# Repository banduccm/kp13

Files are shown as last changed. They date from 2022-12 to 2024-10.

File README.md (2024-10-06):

# Keypad #

This is an attempt to design a serviceable replacement the long-discontinued G13 "gameboard".

## PCB ##

The PCB design depends on symbols from a few libraries:

- <https://github.com/stormbard/Keyboard.pretty> for the hotswap switch footprints
- <https://github.com/drewgates/kb2040-kicad> for the Adafruit KB2040 footprint, symbol, and step file
- <https://grabcad.com/library/kailh-hotswap-mx-1> for the hot-swap socket step file (requires registration)

### Board Layout ###

The G13 had 22 "G" keys, 2 thumb keys, and an analog stick with a click (in addition to some other buttons not
important to this effort).

This initial project contains the main board with 22 keys and 2 pushbuttons intended to be used to switch
layers in QMK. It also includes a header with 2 rows and 6 columns for an expansion board (i.e, the thumb
buttons).

The KB2040 was selected due to easy availability, compatibility with the Pro Micro pinout, and a USB-C port.
Other Pro Micro-compatible boards may work, but take care to skip the D+/D- pins from the KB2040.

## Plates ##

The switch mounting plates for this project were initially designed using swillkb's
[Plate & Case Builder](http://builder.swillkb.com/) tool, then imported into qcad for manipulation.

Experimental baseplates for both the keypad and full-size thumb pod are included, as are 3d-printable spacers
to sit between the plates and PCB.

### Keyboard Layout ###

This layout is used by both the plate builder and the
[Keyboard Layout Editor](http://www.keyboard-layout-editor.com) tool:

```text
[{x:3}, "C0", "C1"],
["G1","G2","G3","G4","G5","G6","G7"],
["G8","G9","G10","G11","G12","G13","G14"],
[{x:0.75,w:1.25},"G15","G16","G17","G18",{w:1.25},"G19"],
[{x:1,w:2},"G20","G21",{w:2},"G22"],
[{x:8.75}, "Stick ↑"],
[{x:7.25}, "G23", "Stick ←", "Stick →"],
[{x:7}, "G24", {x:0.75}, "Stick ↓" ],
[{x:8}, "G25", "G26"]
```

For Via (with some extra design flavor), this is:

```text
[{x:3},"3,4","3,5"],
["0,0","0,1","0,2","0,3","0,4","0,5","1,0"],
["1,1","1,2","1,3","1,4","1,5","2,0","2,1"],
[{x:0.75,w:1.25},"2,2","2,3","2,4","2,5",{w:1.25},"3,0"],
[{x:1,w:2},"3,1","3,2",{w:2},"3,3"],
[{y:0.75,x:8.75,h:0.75},"4,0"],
[{y:-0.75,x:7.25},"5,0"],
[{y:-0.5,x:8.25,h:0.75},"4,1",{h:0.75},"4,3"],
[{y:-0.5,x:7},"5,1"],
[{y:-0.75,x:8.75,h:0.75},"4,2"],
[{y:-0.25,x:8},"5,2","5,3"]

```

 ## Parts ##

 For the first build, the following parts were used:

 ### Plate ###

 The place was ordered from [SendCutSend](https://sendcutsend.com/) in 1.6mm thick 5051 Aluminum.

 ### Electronics ###

 Initial parts were ordered from Adafruit:

- 30x [1N4148 diodes](https://www.adafruit.com/product/1641)
- 20x [6mm Tactile Button switch](https://www.adafruit.com/product/367)
- 40x [Kailh Switch Sockets for MX-compatible Mechanical Keys](https://www.adafruit.com/product/4958)
- 30x [Kailh Mechanical Key Switches - Linear Black](https://www.adafruit.com/product/4953)
- 1x [Adafruit KB2040](https://www.adafruit.com/product/5302)
- ~~1x [GMK Screw-in Stabilizers](https://1upkeyboards.com/shop/parts-and-tools/parts/gmk-screw-in-stabilizers/)~~ _Note: These ended up being incompatible with the plate, see v0.1.0 notes_
- 1x [Durock Plate Mount Stabilizers](https://1upkeyboards.com/shop/parts-and-tools/parts/durock-plate-mount-stabilizers-60-tkl-piano/)

### PCB ###

The PCB was ordered from PCBWay using their Kicad plugin.

## Version Notes ##

### v0.1.0 ###

Generally good news! The parts all fit as expected and the circuit works as designed. No reworks required to
have a functioning 22-key setup.

- The plate is not compatible with the PCB-mount stabilizers.
- The angle on the plate and the angle on the PCB are not the same. This is annoying, but not a functional
 problem.
- n-key rollover works (as expected), but note that QMK defaults to 6KRO. The default keymap uses switch C0
 on Layer 0 to toggle it.

### v0.1.1 ###

Instead of relying on trying to rely on external tools, all the mechanical bits were re-drawn in qcad, which
helpfully makes it extremely simple to import an exported .dxf from KiCAD for tracing and fit checking. The
stabilizer compatibility was not addressed (yet), but at least the angle between the PCB and plate(s) now
aligns.

## v0.2.0 Wishlist ##

During the mechanical design phase, some items were added as a wishlist for a potential second spin of the
"big" board:

- Smaller, optimized thumb-pod connector. Considering using a 1.27mm pitch 10-pin cable (Cortex-M SWD
  connector) to reduce mechanical size.
- Figure out how to use the kb2040's castellated pins to reduce z-height

## Thumb Pods ##

The thumb pod(s) incorporate a 4-way (with diagonals!) thumbstick and 0-4 buttons. There are 2 different
versions: regular (4x 1U MX switch, 1x thumbstick) and mini (2x microswitch, 1x thumbstick). The thumbstick
uses the same matrix positions on each version, so it is possible to populate multiple pods and swap between
them as desired.

The pods feature a notched edge for mounting square against the keypad PCB (or a case holding it). This
ensures the A/B/C/D positions of the thumbstick are square with the keypad.

### Thumbstick ###

- [ALPS RKJXM1015004](https://tech.alpsalpine.com/e/products/detail/RKJXM1015004/)

This thumbstick has 4 switches and can handle diagonal movements as well. It has a "stick click", but this
is not broken out as a dedicated pin, so it's unclear if it is compatible with QMK. In v0.1 of the thumb
pods, the "push" pins are not connected to the key matrix. The "push" pins _are_ on their own net, however,
so they could be hand-wired into the matrix if desired. The same thumbstick is used for both thumb pod
designs.

### Thumb Pod (full size) ###

The regular thumb pod uses the same MX hot-swap sockets and 1U keys as the main keypad to provide 4 switches
surrounding the thumbstick.

Experimental top and bottom plates are provided for the full-size thumb pod.

### Thumb Pod Mini ###

The mini thumb pod closely approximates the original G13 thumb section: two mouse-like microswitches and the
thumbstick. This version will require some sort of housing, as it's not really feasible to hit microswitch
actuators.

#### Electronics ####

- [Kailh GM Microswitch](https://www.kailhswitch.com/micro-switches/mouse-micro-switches/high-click-life-gaming-micro-mouse-switch.html)

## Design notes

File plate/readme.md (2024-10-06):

# Plates

This directory contains drawings for the different plates and spacers used to stack up a full keypad.

They were drawn in qcad, but should be compatible with any tool capable of working with `.dxf` files.

## Keypad

### keypad-plate

This is the top plate for the main keypad into which the switches mount.

### keypad-plate-spacer

This spacer is designed to be printed/manufactured at a thickness of ~3mm (when using 1.6mm-thick material for
the plate - different plate thicknesses may have different needs) and stacks between the PCB and the top
plate.

### keypad-base-plate

This is an experimental baseplate onto which the main keypad can mount. It features a few extra holes for
(theoretical) feet and a slot mechanism for affixing the thumb pod plate.

### keypad-base-plate-spacer

This spacer is designed to be printed/manufactured at a thickness of ~4mm (when using 1.6mm-thick material for
the plate - different plate thicknesses may have different needs) and stacks between the PCB and the base
plate.

## Thumb Pod

At present, plates are only available for the larger of the two thumb pods.

### thumb-pod-plate

This is the top place for the thumb pod into which the switches mount.

### thumb-pod-plate-spacer

This is really just a 3.4mm ID / 7mm OD / 3mm thick washer, because there is precious little space on top of
the thumb pod PCB. Use 3, one for each mounting hole.

### thumb-pod-base-plate

This is an experimental baseplate onto which the thumb pod can mount. It features a few extra holes for
(theoretical) feed and a slot mechanism for attaching to the main keypad.

### thumb-pod-base-plate-spacer

This spacer is designed to be printer/manufactured at a thickness of ~4mm (when using 1.6mm-thick material for
the plate - different plate thicknesses may have different needs) and stacks between the PCB and the base
plate.

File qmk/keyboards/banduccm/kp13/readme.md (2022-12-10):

# keypad

This is an attempt to design a serviceable replacement the long-discontinued G13 "gameboard".

* Keyboard Maintainer: [Mike Banducci](https://github.com/banduccm)
* Hardware Supported:
    * [Adafruit KB2040](https://www.adafruit.com/product/5302)
    * [Custom PCB](https://bitbucket.org/banduccm/keypad/src/master/)

Build example for this keyboard (after setting up your build environment):
```
qmk compile -kb keypad -km default
```

Flashing example for this keyboard:
```
qmk flash -kb keypad -km default
```

See the [build environment setup](https://docs.qmk.fm/#/getting_started_build_tools) and the [make instructions](https://docs.qmk.fm/#/getting_started_make_guide) for more information. Brand new to QMK? Start with our [Complete Newbs Guide](https://docs.qmk.fm/#/newbs).

## Bootloader

Enter the bootloader in 3 ways:

* **Bootmagic reset**: Hold down the key at (0,0) in the matrix (usually the top left key or Escape) and plug in the keyboard
* **Physical reset button**: Briefly press the button on the back of the PCB - some may have pads you must short instead
* **Keycode in layout**: Press the key mapped to `QK_BOOT` if it is available

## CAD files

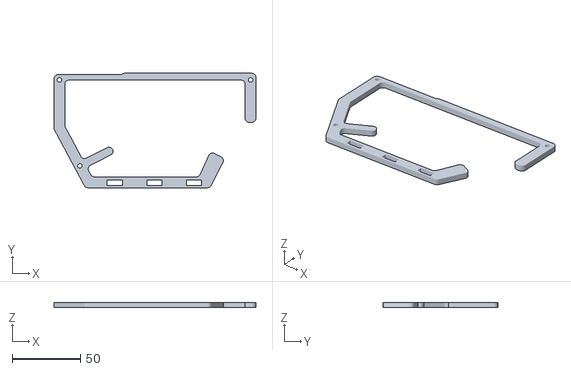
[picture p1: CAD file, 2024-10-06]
plate/keypad-base-plate-spacer-0.1.stl
148.0 x 83.9 x 4.00

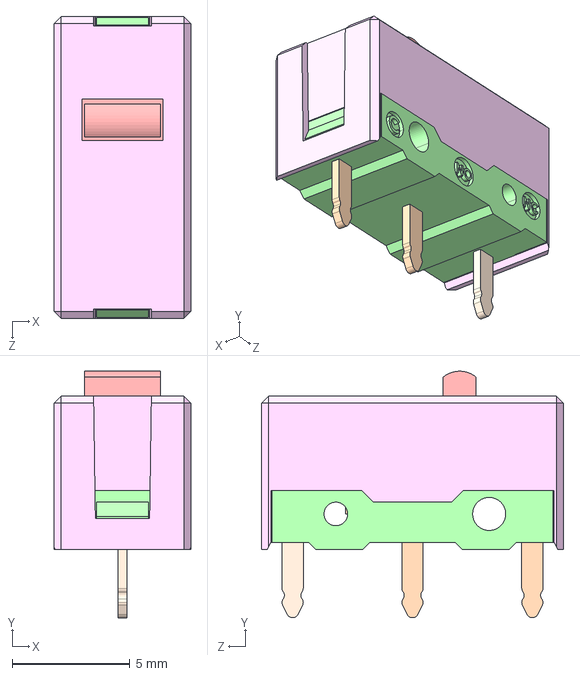
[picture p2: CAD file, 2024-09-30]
thumb_pod/models/SWITCH_MOUSE.STEP
5.80 x 10.4 x 12.8 mm

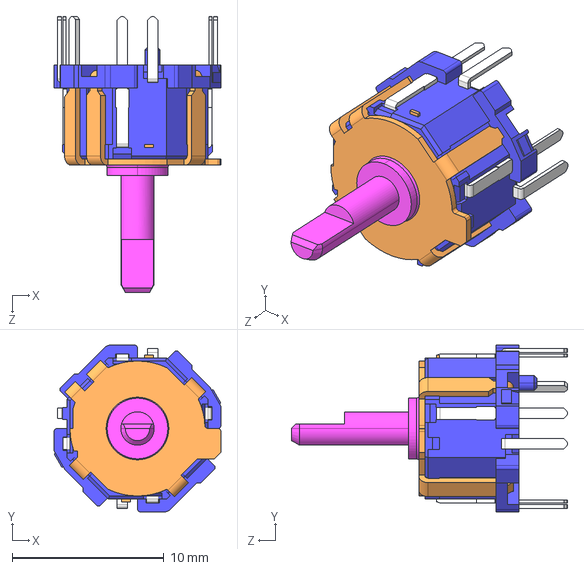
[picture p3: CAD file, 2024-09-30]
thumb_pod/models/RKJXM1015004.STEP
11.0 x 11.0 x 18.2 mm

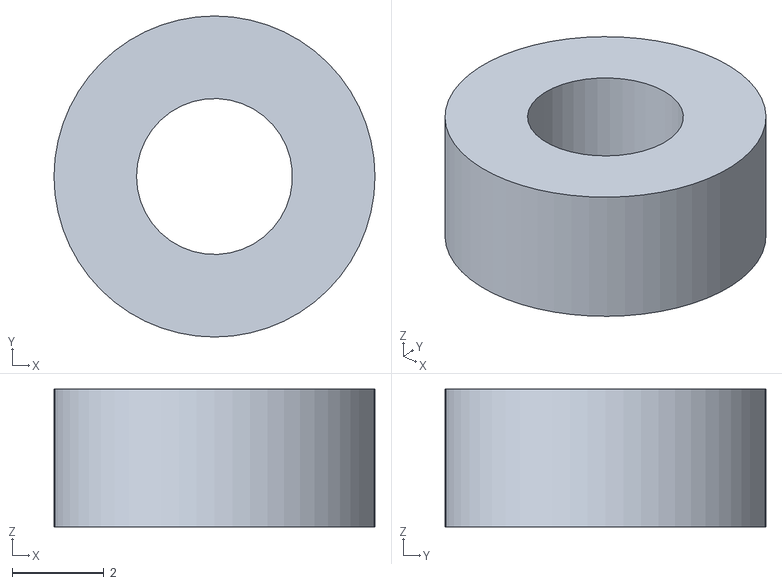
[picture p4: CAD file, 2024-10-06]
plate/thumb-pod-plate-spacer-0.1.stl
7.00 x 7.00 x 3.00

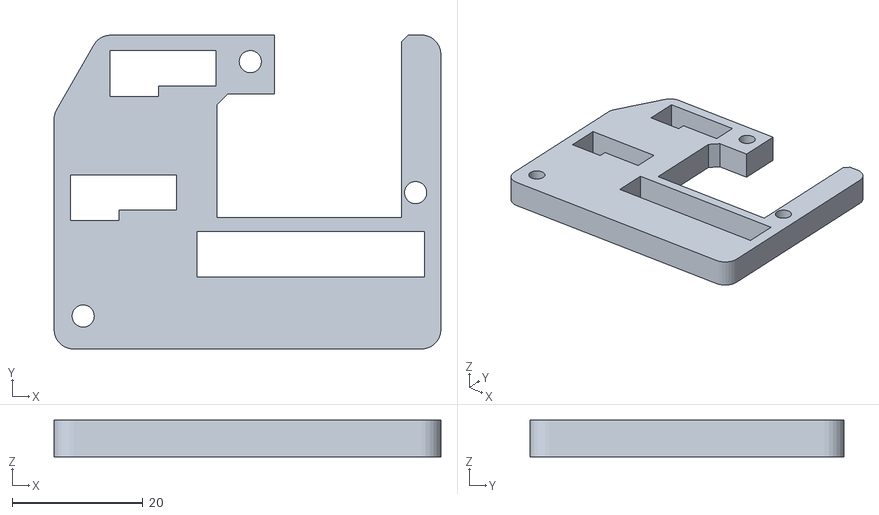
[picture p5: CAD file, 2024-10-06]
plate/thumb-pod-base-plate-spacer-0.1.stl
59.2 x 48.0 x 5.60

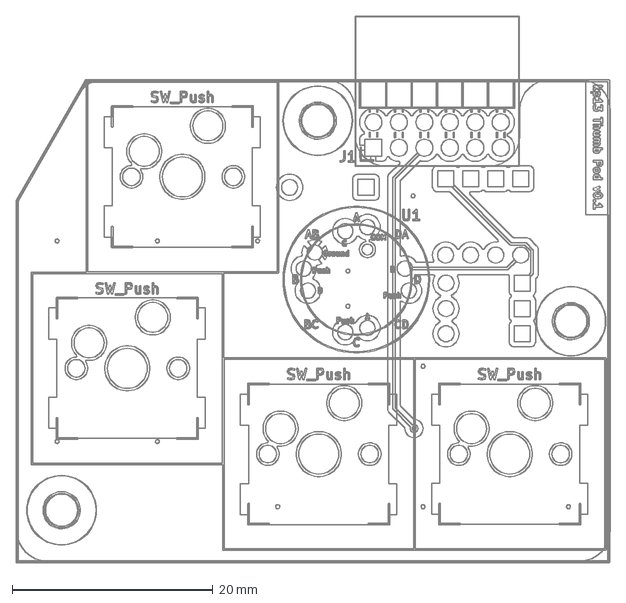
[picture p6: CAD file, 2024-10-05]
plate/thumb-pod-plate-0.1.dxf
59.2 x 54.5 mm

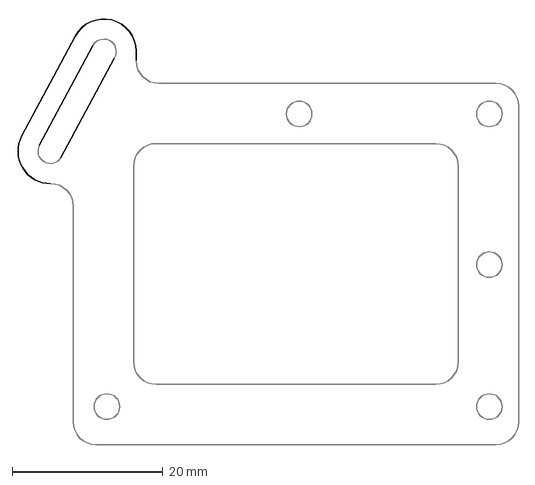
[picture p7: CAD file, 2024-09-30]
plate/thumb-pod-base-plate-0.1.dxf
66.7 x 56.9 mm

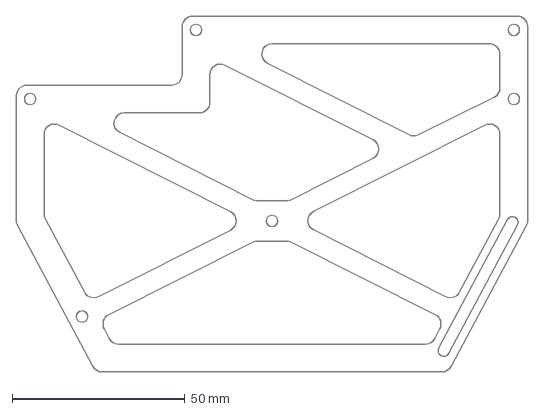
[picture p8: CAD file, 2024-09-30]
plate/keypad-base-plate-0.1.dxf
148.0 x 103.0 mm

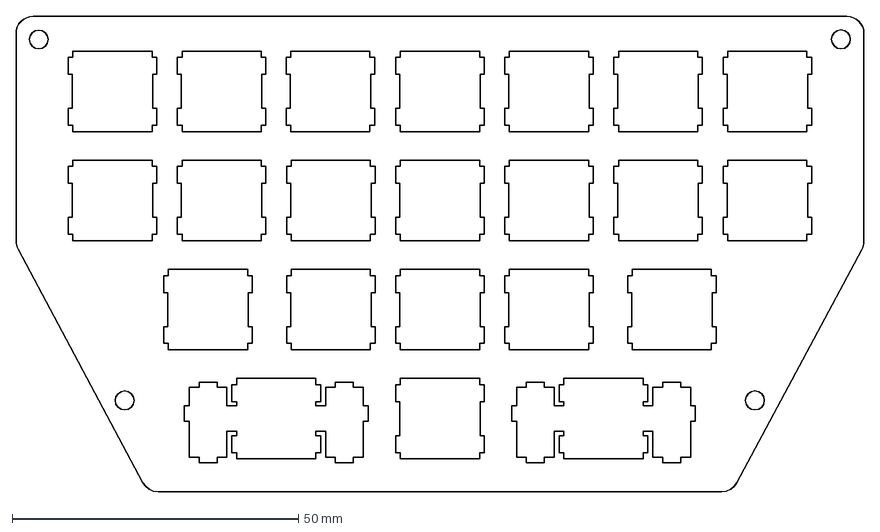
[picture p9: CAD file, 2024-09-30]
plate/keypad-plate-0.1.dxf
148.0 x 83.0 mm

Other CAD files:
plate/keypad-plate-spacer-0.1.stl
plate/keypad-base-plate-spacer-0.1.dxf
plate/keypad-plate-spacer-0.1.dxf
plate/thumb-pod-base-plate-spacer-0.1.dxf
plate/thumb-pod-plate-spacer-0.1.dxf

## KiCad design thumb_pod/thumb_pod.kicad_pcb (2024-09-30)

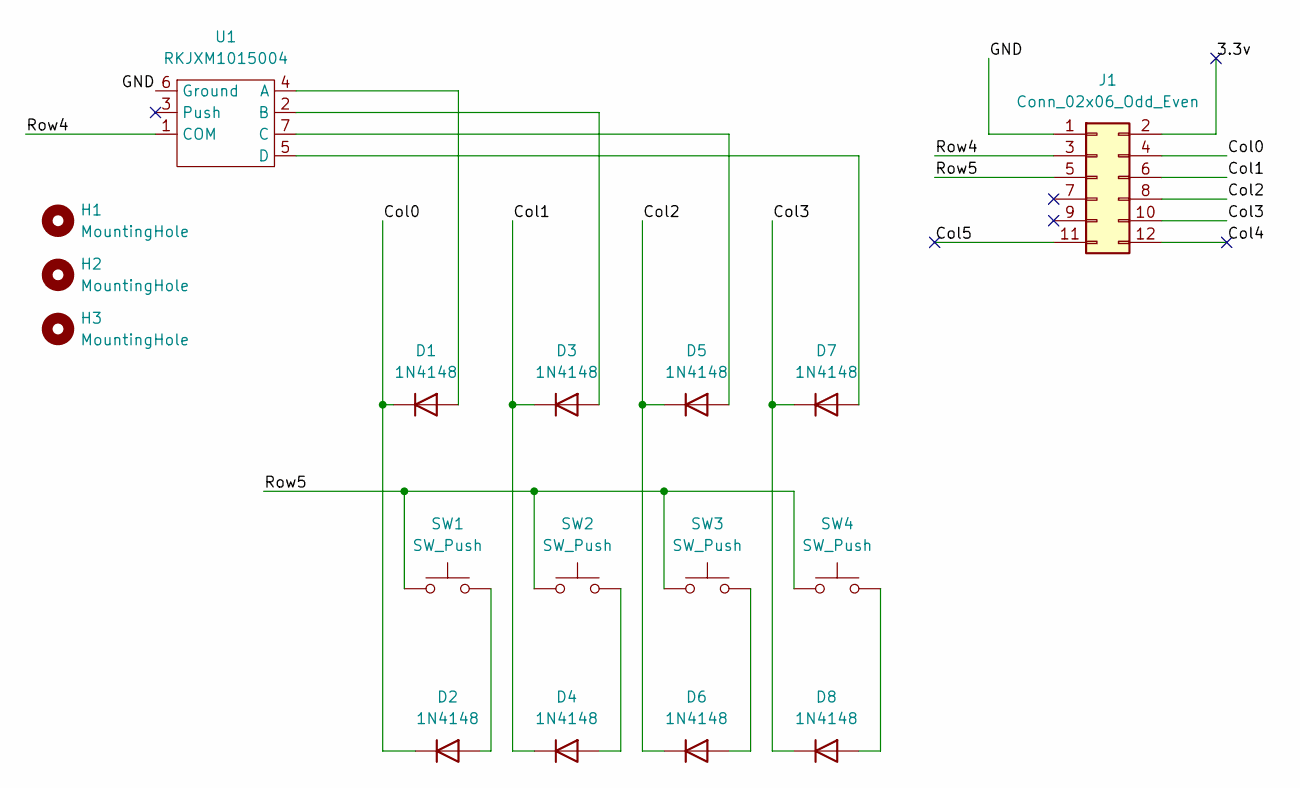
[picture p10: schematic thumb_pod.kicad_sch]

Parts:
D1, D2, D3, D4, D5, D6, D7, D8: 1N4148; D_DO-35_SOD27_P7.62mm_Horizontal
H1, H2, H3: MountingHole; MountingHole_3.2mm_M3
J1: Conn_02x06_Odd_Even; PinHeader_2x06_P2.54mm_Horizontal
SW1, SW2, SW3, SW4: SW_Push; MXOnly-1U-Hotswap
U1: RKJXM1015004

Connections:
/3.3v: J1.2
/Col0: D1.1 (K), D2.1 (K), J1.4
/Col1: D3.1 (K), D4.1 (K), J1.6
/Col2: D5.1 (K), D6.1 (K), J1.8
/Col3: D7.1 (K), D8.1 (K), J1.10
/Col4: J1.12
/Col5: J1.11
/GND: J1.1, U1.6 (Ground)
/Row4: J1.3, U1.1 (COM)
/Row5: J1.5, SW1.1, SW2.1, SW3.1, SW4.1
unnamed: D1.2 (A), U1.4 (A)
unnamed: D2.2 (A), SW1.2
unnamed: D3.2 (A), U1.2 (B)
unnamed: D4.2 (A), SW2.2
unnamed: D5.2 (A), U1.7 (C)
unnamed: D6.2 (A), SW3.2
unnamed: D7.2 (A), U1.5 (D)
unnamed: D8.2 (A), SW4.2

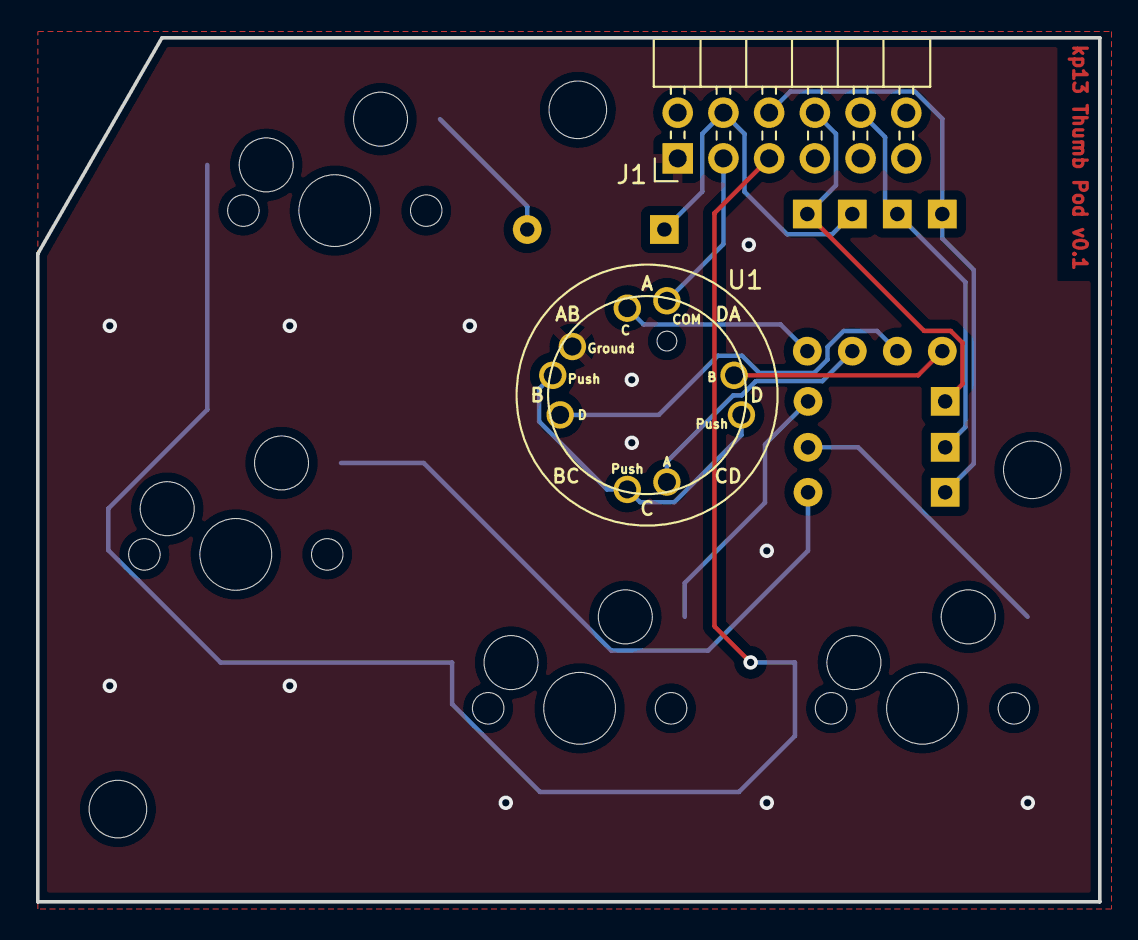
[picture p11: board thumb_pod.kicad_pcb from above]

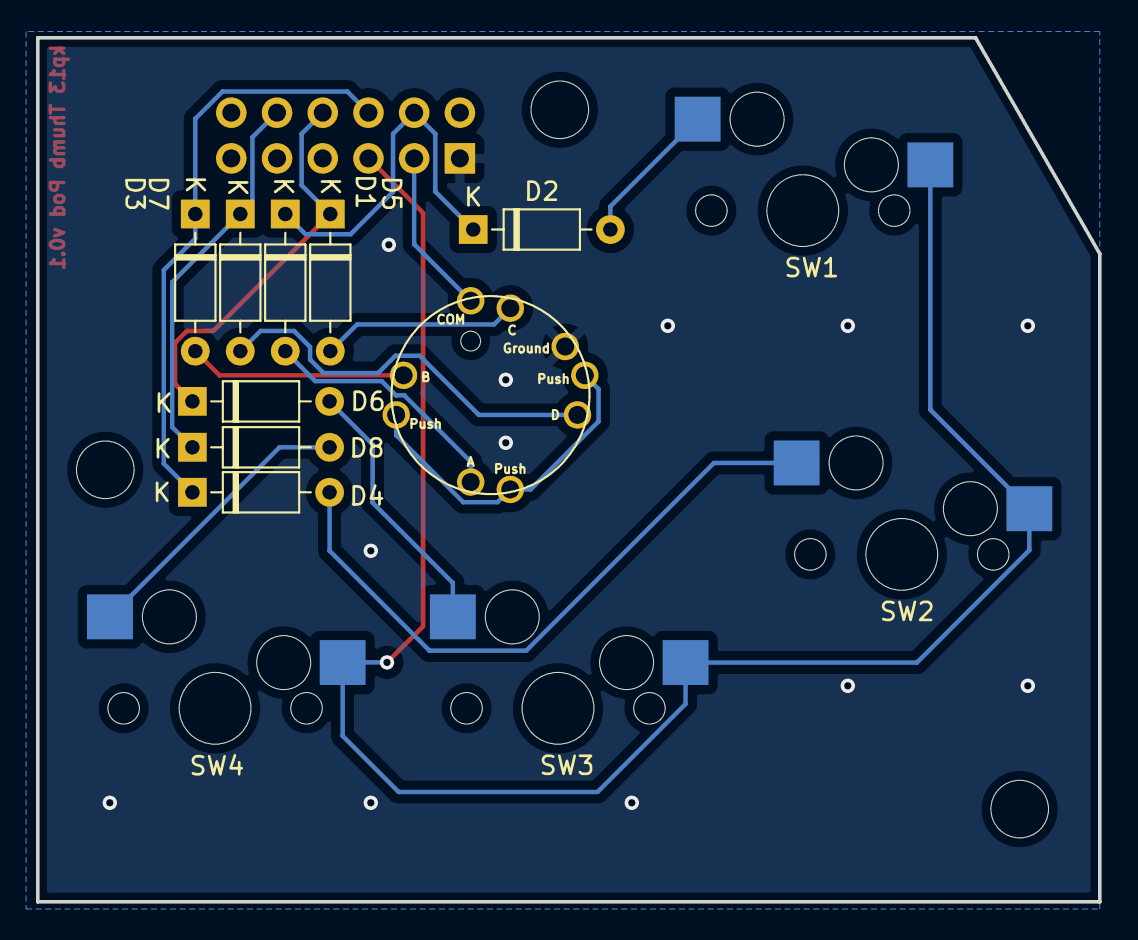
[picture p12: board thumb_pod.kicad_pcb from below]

Board: 2 copper layers, 59.0 x 48.0 mm, 17 parts (8 on the bottom side), 15 nets.

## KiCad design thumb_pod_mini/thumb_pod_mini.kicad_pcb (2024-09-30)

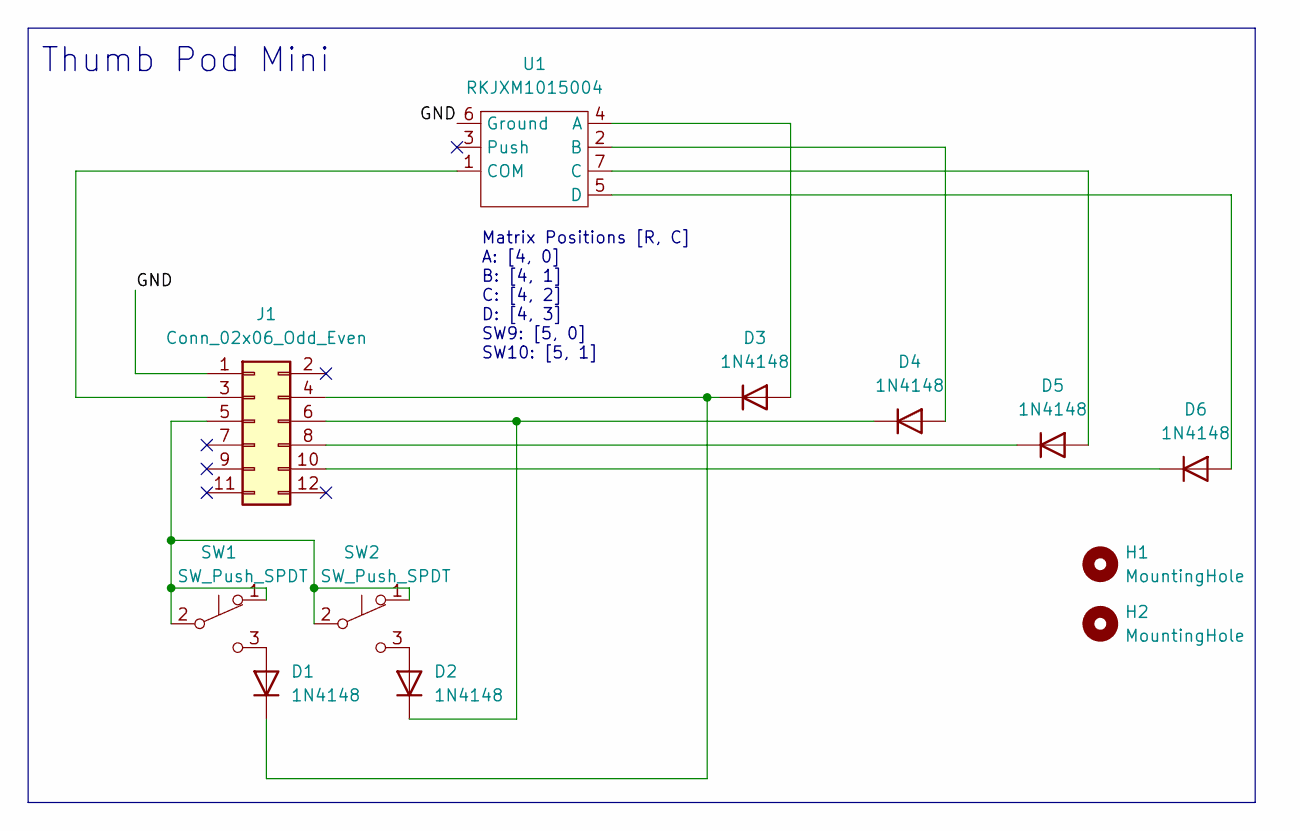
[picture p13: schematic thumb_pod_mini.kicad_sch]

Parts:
D1, D2, D3, D4, D5, D6: 1N4148; D_DO-35_SOD27_P7.62mm_Horizontal
H1, H2: MountingHole; MountingHole_3.2mm_M3
J1: Conn_02x06_Odd_Even; PinHeader_2x06_P2.54mm_Horizontal
SW1, SW2: SW_Push_SPDT; kailh_gm_microswitch
U1: RKJXM1015004

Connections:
/GND: J1.1, U1.6 (Ground)
unnamed: D1.1 (K), D3.1 (K), J1.4
unnamed: D1.2 (A), SW1.3 (C)
unnamed: D2.1 (K), D4.1 (K), J1.6
unnamed: D2.2 (A), SW2.3 (C)
unnamed: D3.2 (A), U1.4 (A)
unnamed: D4.2 (A), U1.2 (B)
unnamed: D5.1 (K), J1.8
unnamed: D5.2 (A), U1.7 (C)
unnamed: D6.1 (K), J1.10
unnamed: D6.2 (A), U1.5 (D)
unnamed: J1.3, U1.1 (COM)
unnamed: J1.5, SW1.1 (A), SW1.2 (B), SW2.1 (A), SW2.2 (B)

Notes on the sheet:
Matrix Positions [R, C] A: [4, 0] B: [4, 1] C: [4, 2] D: [4, 3] SW9: [5, 0] SW10: [5, 1]
Thumb Pod Mini

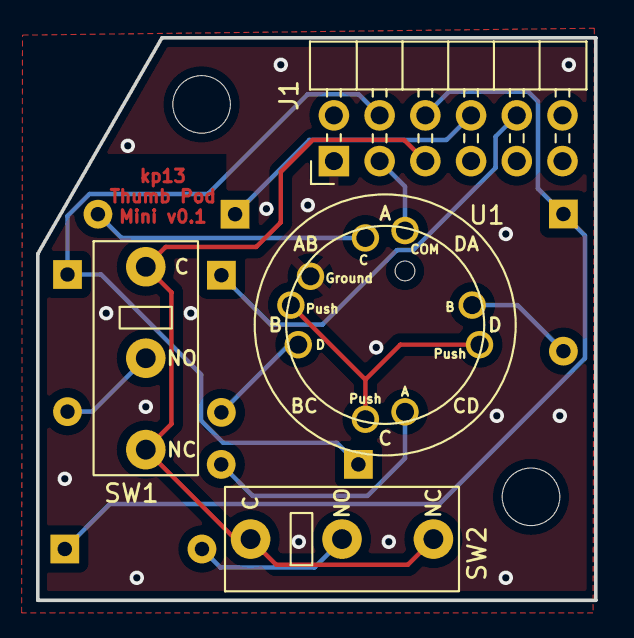
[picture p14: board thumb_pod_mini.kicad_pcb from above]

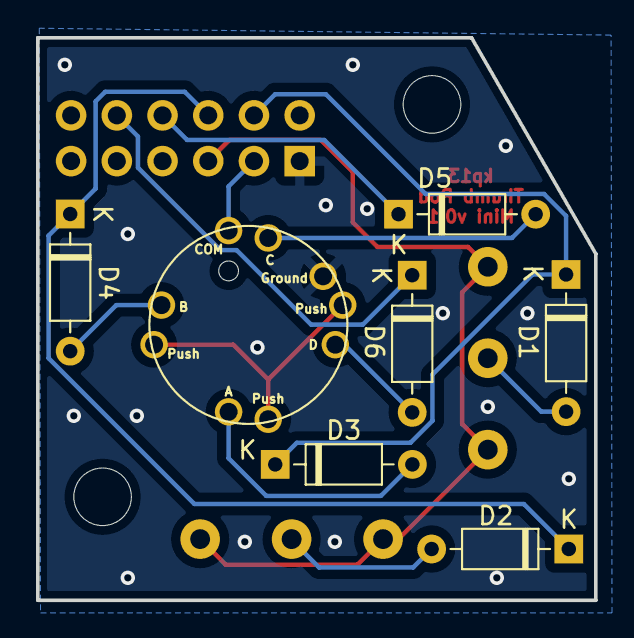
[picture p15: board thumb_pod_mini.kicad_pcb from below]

Board: 2 copper layers, 31.0 x 31.2 mm, 12 parts (6 on the bottom side), 13 nets.

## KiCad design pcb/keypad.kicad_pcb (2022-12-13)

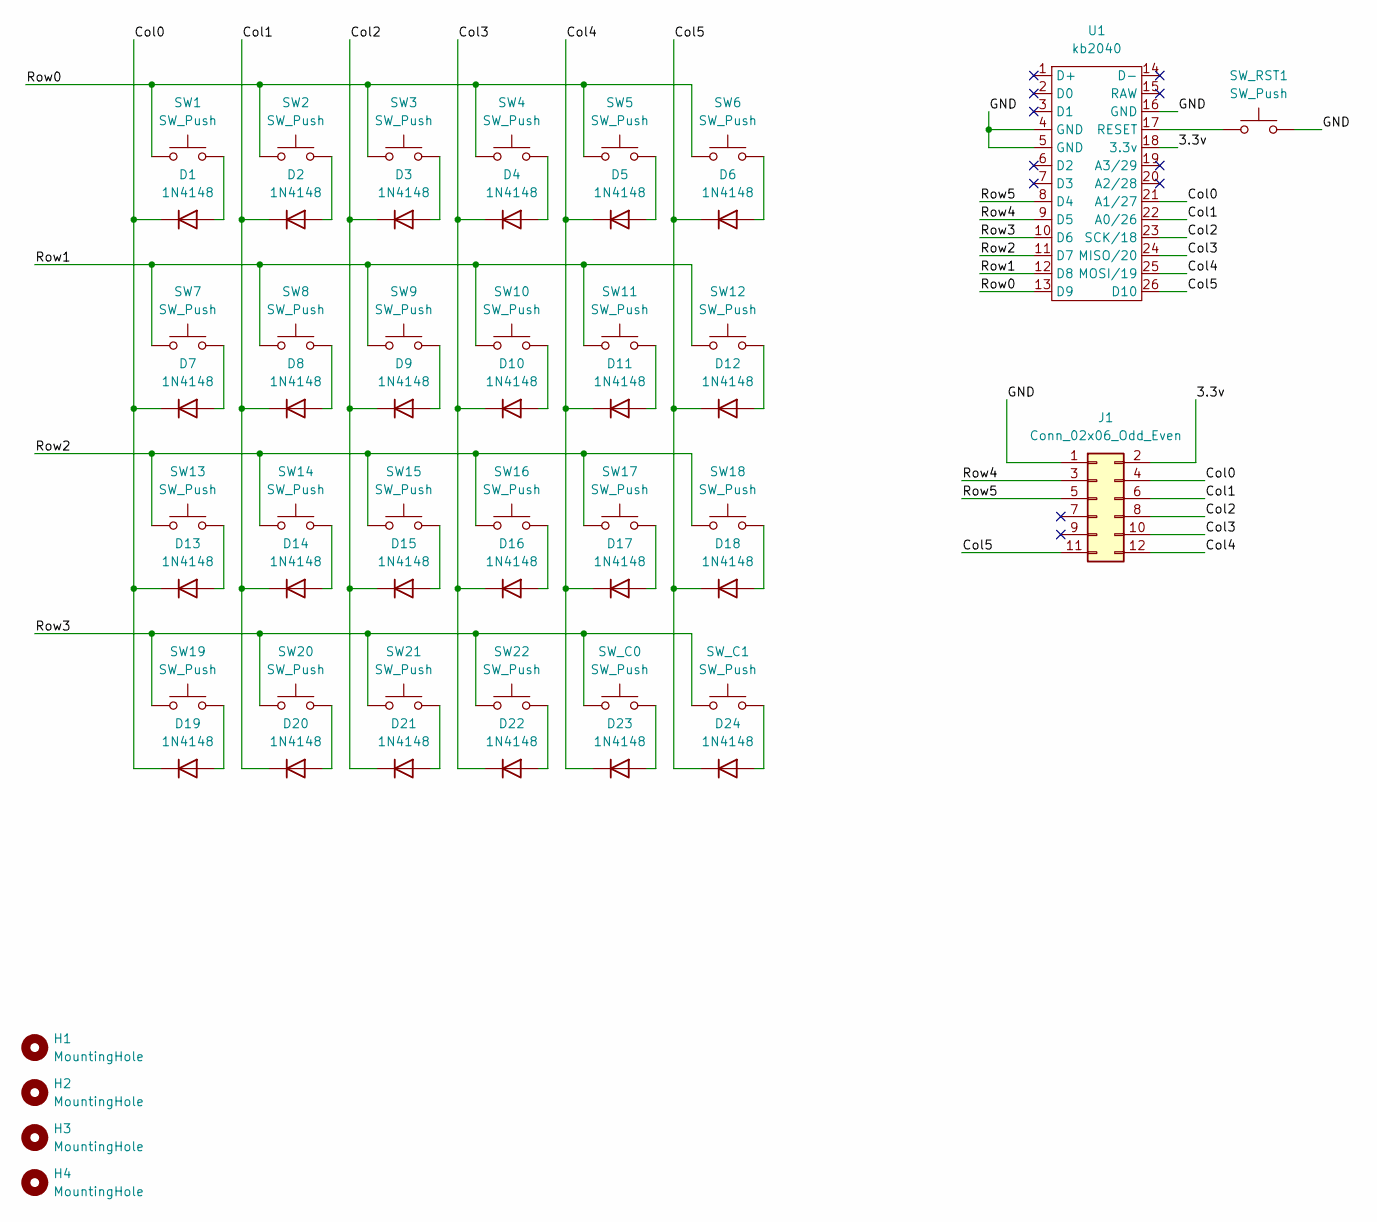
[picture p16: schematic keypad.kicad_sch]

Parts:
D1, D2, D3, D4, D5, D6, D7, D8, D9, D10, D11, D12, D13, D14, D15, D16, D17, D18, D19, D20, D21, D22, D23, D24: 1N4148; D_DO-35_SOD27_P7.62mm_Horizontal
H1, H2, H3, H4: MountingHole; MountingHole_3.2mm_M3
J1: Conn_02x06_Odd_Even; PinHeader_2x06_P2.54mm_Horizontal
SW1, SW2, SW3, SW4, SW5, SW6, SW7, SW8, SW9, SW10, SW11, SW12, SW13, SW14, SW16, SW17, SW18, SW21: SW_Push; MXOnly-1U-Hotswap
SW15, SW19: SW_Push; MXOnly-1.25U-Hotswap
SW20, SW22: SW_Push; MXOnly-2U-Hotswap
SW_C0, SW_C1: SW_Push; SW_PUSH_6mm_H7.3mm
SW_RST1: SW_Push; SW_PUSH_6mm_H7.3mm
U1: kb2040

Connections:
/3.3v: J1.2, U1.18 (3.3v)
/Col0: D1.1 (K), D7.1 (K), D13.1 (K), D19.1 (K), J1.4, U1.21 (A1/27)
/Col1: D2.1 (K), D8.1 (K), D14.1 (K), D20.1 (K), J1.6, U1.22 (A0/26)
/Col2: D3.1 (K), D9.1 (K), D15.1 (K), D21.1 (K), J1.8, U1.23 (SCK/18)
/Col3: D4.1 (K), D10.1 (K), D16.1 (K), D22.1 (K), J1.10, U1.24 (MISO/20)
/Col4: D5.1 (K), D11.1 (K), D17.1 (K), D23.1 (K), J1.12, U1.25 (MOSI/19)
/Col5: D6.1 (K), D12.1 (K), D18.1 (K), D24.1 (K), J1.11, U1.26 (D10)
/GND: J1.1, SW_RST1.2, U1.4 (GND), U1.5 (GND), U1.16 (GND)
/Row0: SW1.1, SW2.1, SW3.1, SW4.1, SW5.1, SW6.1, U1.13 (D9)
/Row1: SW7.1, SW8.1, SW9.1, SW10.1, SW11.1, SW12.1, U1.12 (D8)
/Row2: SW13.1, SW14.1, SW15.1, SW16.1, SW17.1, SW18.1, U1.11 (D7)
/Row3: SW19.1, SW20.1, SW21.1, SW22.1, SW_C0.1, SW_C1.1, U1.10 (D6)
/Row4: J1.3, U1.9 (D5)
/Row5: J1.5, U1.8 (D4)
unnamed: D1.2 (A), SW1.2
unnamed: D2.2 (A), SW2.2
unnamed: D3.2 (A), SW3.2
unnamed: D4.2 (A), SW4.2
unnamed: D5.2 (A), SW5.2
unnamed: D6.2 (A), SW6.2
unnamed: D7.2 (A), SW7.2
unnamed: D8.2 (A), SW8.2
unnamed: D9.2 (A), SW9.2
unnamed: D10.2 (A), SW10.2
unnamed: D11.2 (A), SW11.2
unnamed: D12.2 (A), SW12.2
unnamed: D13.2 (A), SW13.2
unnamed: D14.2 (A), SW14.2
unnamed: D15.2 (A), SW15.2
unnamed: D16.2 (A), SW16.2
unnamed: D17.2 (A), SW17.2
unnamed: D18.2 (A), SW18.2
unnamed: D19.2 (A), SW19.2
unnamed: D20.2 (A), SW20.2
unnamed: D21.2 (A), SW21.2
unnamed: D22.2 (A), SW22.2
unnamed: D23.2 (A), SW_C0.2
unnamed: D24.2 (A), SW_C1.2
unnamed: SW_RST1.1, U1.17 (RESET)

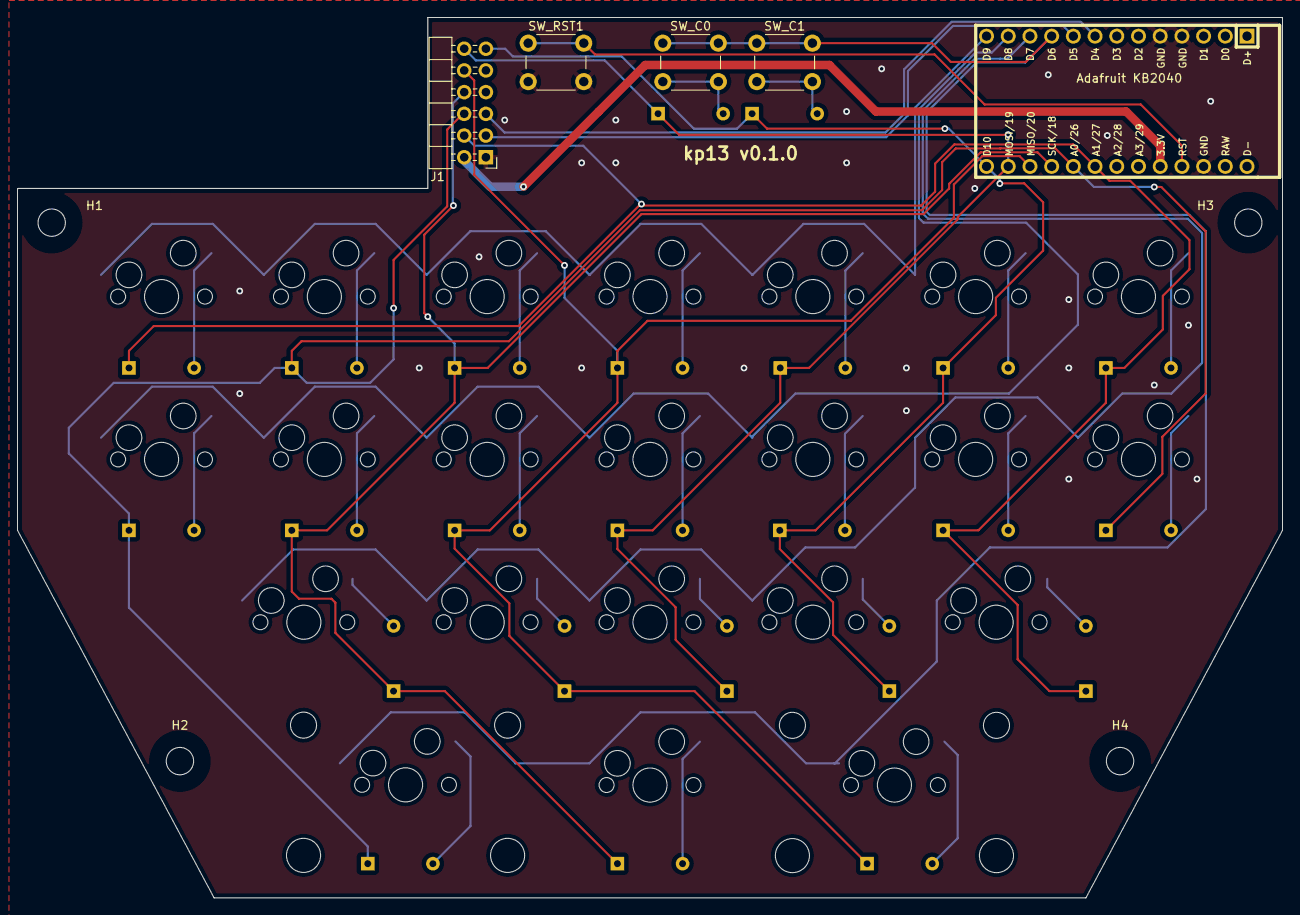
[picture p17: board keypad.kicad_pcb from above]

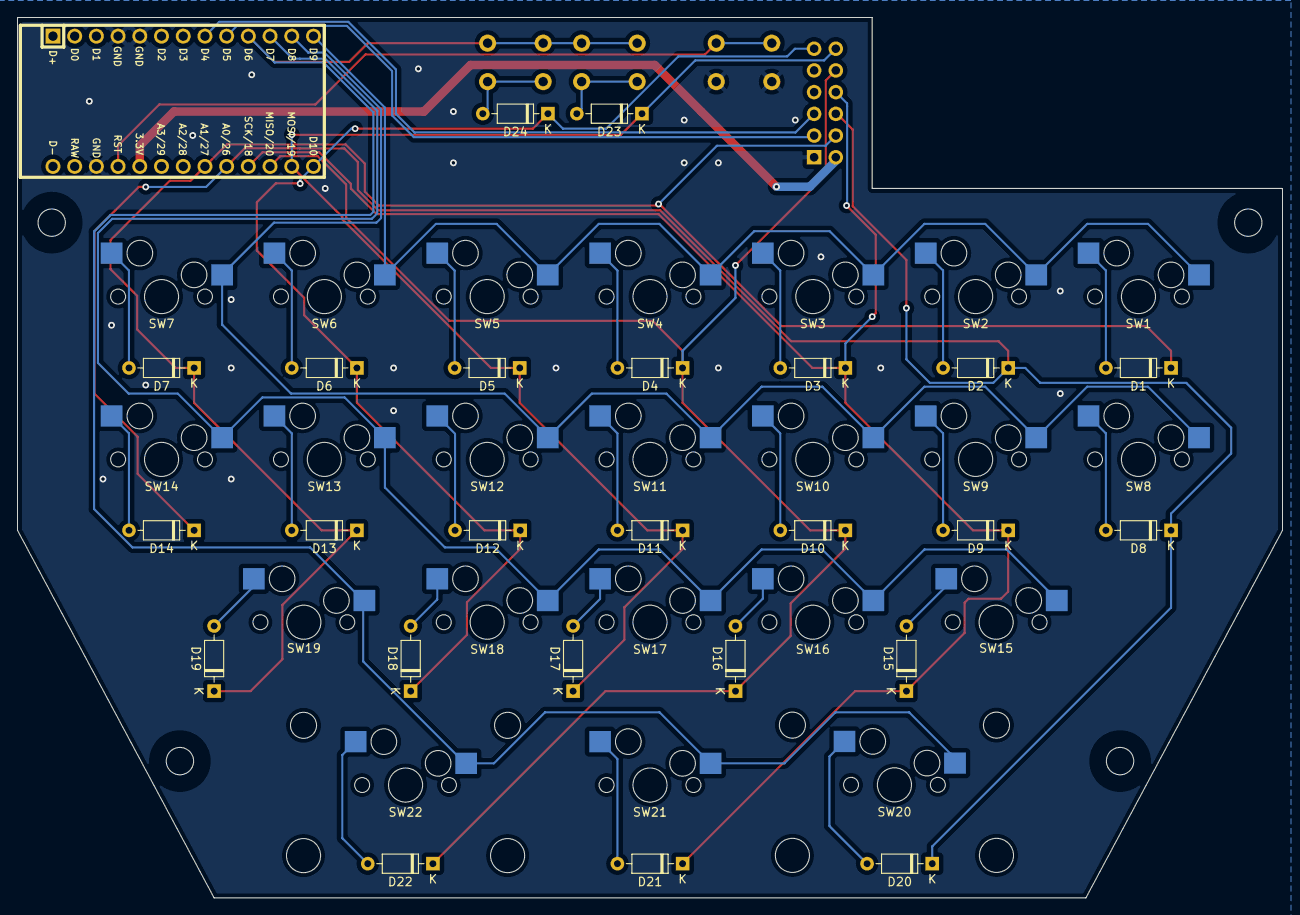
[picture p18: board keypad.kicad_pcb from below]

Board: 2 copper layers, 148.0 x 103.0 mm, 55 parts (24 on the bottom side), 39 nets.

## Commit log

2022-07-12 - Initial board design, layout - Initial readme
    [keypad.kicad_pcb, keypad.kicad_sch]
2022-07-12 - Added a reset button for the controller - Moved the through-hole diodes to not interfere with the switches
    [keypad.kicad_pcb, keypad.kicad_sch]
2022-12-04 - Added plate details - Fixed the spacing of non-1U keys on the PCB layout
    [keypad.kicad_pcb, plate-outline-0.1.dxf]
2022-12-07 - Switched to the KB2040 - Modified the pin header to remove some silk screen sections
    [keypad.kicad_pcb, keypad.kicad_sch]
2022-12-10 Added QMK board definition files
2022-12-11 Moved necessary symbols into the project library - (I don't know if this comes with license issues; if there's a problem let me know and I can remove the symbols)
    [keypad.kicad_pcb, keypad.kicad_sch]
2022-12-13 - Marked NC pins - Updated diode symbols
    [keypad.kicad_pcb, keypad.kicad_sch]
2024-09-30 - BOM update to reflect the actual stabilizers used
2024-09-30 - First attempt at a thumb pod design
    [thumb_pod.kicad_pcb, thumb_pod.kicad_sch]
2024-09-30 - Added multiple positions for each switch to allow for tweaking
    [thumb_pod.kicad_pcb, thumb_pod.kicad_sch]
2024-09-30 - Added a board label and version
    [thumb_pod.kicad_pcb]
2024-09-30 - Added a preliminary "mini" thumb pod with only the directional stick - Added mouse bite footprint from Panelization.pretty
    [thumb_pod.kicad_pcb, thumb_pod.kicad_sch]
2024-09-30 - Added experimental alternate layouts for the thumb pod - Attempted some DIY panelization
    [thumb_pod.kicad_pcb, thumb_pod.kicad_sch]
2024-09-30 - Updated the "mini" thumb pod with an angled PCB edge
    [thumb_pod.kicad_pcb]
2024-09-30 - Rearranged sub-boards to (hopefully) make manufacturing easier - Fixed the schematic to better isolate each thumb pod version
    [thumb_pod.kicad_pcb, thumb_pod.kicad_sch]
2024-09-30 - Rearranged repository - Updated readme with thumb pod details
    [thumb_pod.kicad_pcb, thumb_pod.kicad_sch]
2024-09-30 - Removed "micro" thumb pod - Added kailh gm microswitch footprint - Switch to kail gm microswitches for the "mini" thumb pod - Reduced size of joystick silkscreen
    [thumb_pod.kicad_pcb, thumb_pod.kicad_sch]
2024-09-30 - Updated the kailh gm switch footprint to match the SPDT symbol - Updated the mini thumb pod switches to allow them to be placed in either orientation
    [thumb_pod.kicad_pcb, thumb_pod.kicad_sch]
2024-09-30 - Added models for the thumbstick and microswitch - thumbstick: https://tech.alpsalpine.com/e/products/detail/RKJXM1015004/ - microswitch: https://grabcad.com/library/tiny-switch-kailh-mouse-1
    [RKJXM1015004.STEP, SWITCH_MOUSE.STEP, thumb_pod.kicad_pcb]
2024-09-30 - Abandoned the multi-position 1U switch experiment - Added a notch to the thumb pod (normal sized) - Adjusted button placement on the larger thumb pod based on testing - Updated the readme
    [thumb_pod.kicad_pcb, thumb_pod.kicad_sch]
2024-09-30 - Split the thumb pod PCBs
    [thumb_pod.kicad_pcb, thumb_pod.kicad_sch, thumb_pod_mini.kicad_pcb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]
2024-09-30 - Updated keymap and matrix for the default thumb pod - Added a thumb pod plate design
    [thumb-pod-plate-0.1.dxf]
2024-09-30 - Experimental plate updates - (untested) base plates for the keypad and larger thumb pod - (untested) keypad plate update with correct angles and slightly enlarged key cuts
    [keypad-base-plate-0.1.dxf, keypad-plate-0.1.dxf, thumb-pod-base-plate-0.1.dxf]
2024-10-05 - Updated readme - Rounded thumb pod plate corners to be consistent - Initial work on top/bottom keypad plate spacers
    [keypad-base-plate-spacer-0.1.dxf, keypad-plate-spacer-0.1.dxf, thumb-pod-plate-0.1.dxf]
2024-10-06 - Continued work on mechanical bits - Added a plate readme - Added .stls for the spacers - Added thumb pod spacer files
    [keypad-base-plate-spacer-0.1.stl, keypad-plate-spacer-0.1.stl, plate-outline-0.1.dxf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]
2024-10-06 - Corrected cutouts for the keypad baseplate spacer
    [keypad-base-plate-spacer-0.1.dxf, keypad-base-plate-spacer-0.1.stl]
2024-10-06 - Additional keypad/baseplate spacer fixes
    [keypad-base-plate-spacer-0.1.dxf, keypad-base-plate-spacer-0.1.stl]
